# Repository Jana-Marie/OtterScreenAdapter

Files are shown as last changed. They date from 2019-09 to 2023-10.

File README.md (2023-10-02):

# OtterScreenAdapter

It turns out that modern screens/panels like the LP097QX1-SPA1 from LG have a eDP interface, which is only DP (DisplayPort) but without a standard connector. You can buy such a screen for ~40€ and with the OtterScreenAdapter (part cost: ~10€) you can convert it into an external 2048x1536px monitor.

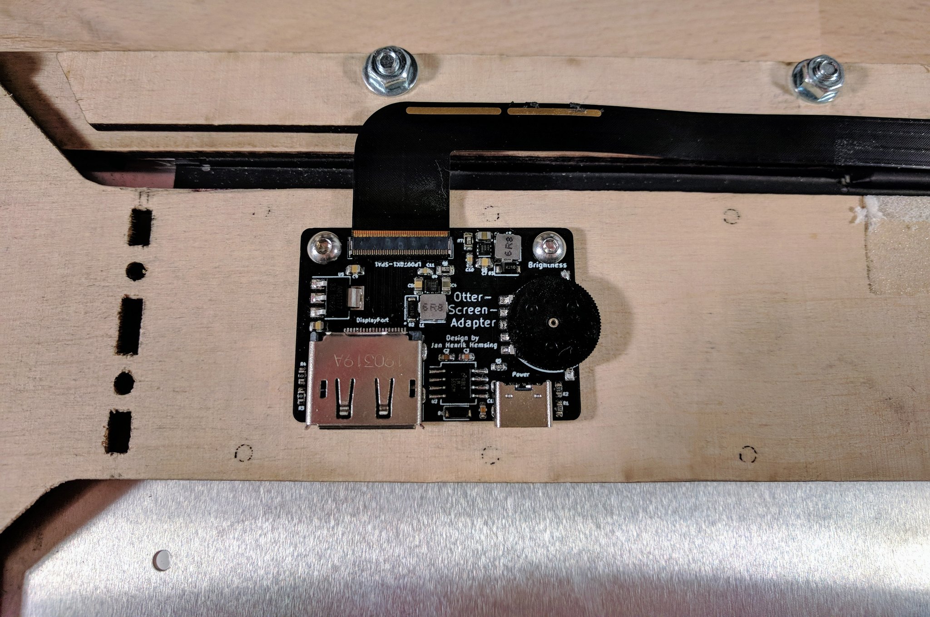
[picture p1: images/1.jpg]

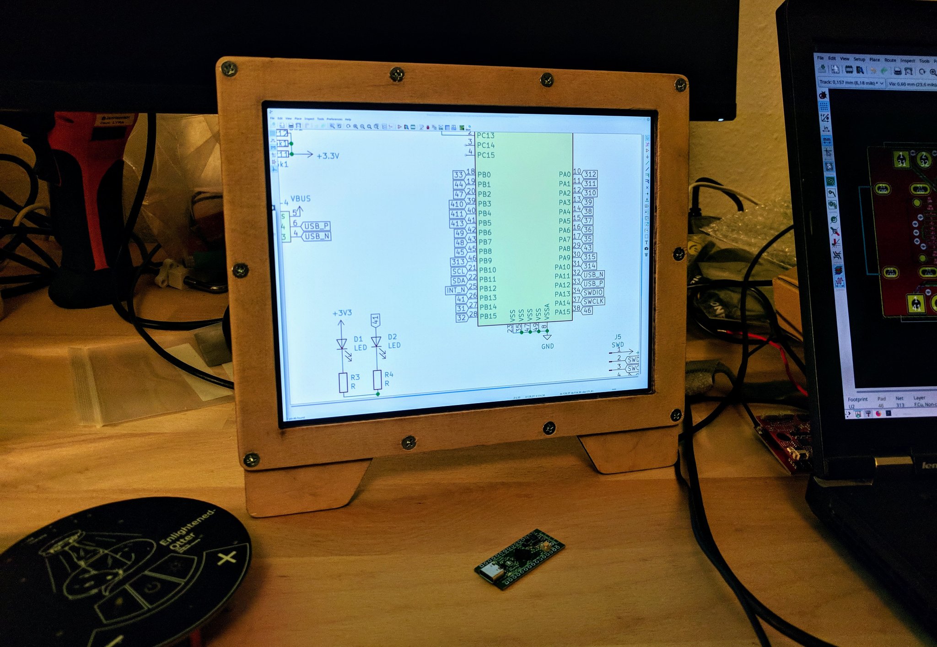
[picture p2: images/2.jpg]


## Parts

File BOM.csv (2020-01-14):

References | Qty | Description | Manufacturer | MPN | Manufacturer | MPN | Manufacturer | MPN | Manufacturer | MPN | Digikey | Mouser | RS | Newark | Farnell | LCSC | Link 1 | Link 2
C10,C11 | 2 | 220nF 50V | Yageo | CC0603KRX7R7BB224 | Murata | GRM188R71E224KA88D |  |  |  |  | 490-1293-1-ND | 81GRM188R71E224KA88 | 6242496 | 68R4772 | 1828900 | C21120
U3,U4 | 2 | TPS61160A |  |  |  |  |  |  |  |  | 296-24308-1-ND | 595TPS61160ADRVR | 1456783 | 33AH5278 | 3006048
C8,C9,C7,C5 | 4 | 470nF 0805 |  |  |  |  |  |  |  |  | 478-1403-1-ND |  |  |  |  | C13967
U5 | 1 | 1117-3.3 |  |  |  |  |  |  |  |  | LM1117DTX-3.3/NOPBCT-ND | 595REG11173.3/2K5 | 8095407 | 29AH7865 | 2111733 | C6186
J1 | 1 | 47272-0001 |  |  |  |  |  |  |  |  | WM19271CT-ND | 538472720001 | 8007021 | 28X2778 | 2396153 |  | https://www.ebay.de/itm/5PCS-X-47272-0001-MOLEX-connector/333130808543 | https://de.aliexpress.com/item/32985577405.html
U2 | 1 | NE555 |  |  |  |  |  |  |  |  | 296-1411-5-ND | 595NE555P | 8234043P | 05M4241 | 9589880 | C7593
R8 | 1 | RK14J12R0A0C | ALPS | RK14J12R0A0C |  |  |  |  |  |  |  | 688-RK14J12R0A0C |  |  |  | C231766
R7,R6 | 2 | 0.8Ohm 0805 |  |  |  |  |  |  |  |  | HCJ0805ZT0R00CT-ND |  |  |  |  | C25267
R5 | 1 | 100Ohm 0603 | Yageo | RC0603FR-07100RL | Panasonic | ERJ-3EKF1000V | Vishay | CRCW0603100RFKEA |  |  | 311-100HRDKR-ND | 71CRCW0603100E3 | 8206748 | 64R5307 | 2303059 | C22775
L2,L1 | 2 | 22uH 4040 |  |  |  |  |  |  |  |  | 732-10762-1-ND | 45522UHF001033E | 1718447P | 26M5905 | 1186787 | C408340
D3,D2,D1 | 2 | SS34 SOD-123 |  |  |  |  |  |  |  |  | SS34LWRVGCT-ND |  |  |  |  | C84632
C6,C4 | 2 | 10uF 0805 | Murata | GRM21BR61C106KE15L |  |  |  |  |  |  | 490-3886-1-ND | 81GRM21BR61C106KE15 | 7236039 | 35R0687 | 1762635 | C15850
C3 | 1 | 1n 0603 | Yageo | CC0603KRX7R9BB102 | Murata | GRM1885C1H102JA01D | Yageo | CC0603KRX7R9BB102 | Murata | GRM188R71H102KA01D | 311-1080-6-ND | 603CC603KRX7R9BB102 | 7235795 | 68R4786 | 1362437 | C1588
C2,C1 | 2 | 100n 0603 | Yageo | CC0603KRX7R9BB104 | Murata | GRM188R71H104KA93D |  |  |  |  | 490-1519-6-ND | 603CC603KRX7R9BB104 | 7235676 | 68R4788 | 8820023 | C14663
J2 | 1 | TYPE-C-31-M-17 | Korean Hroparts Elec | TYPE-C-31-M-17 |  |  |  |  |  |  |  |  |  |  |  | C283540
R4,R3 | 2 | 0Ohm 0603 | Yageo | RC0603JR-070RL | Panasonic | ERJ-3GEY0R00V | Vishay | CRCW06030000Z0EA |  |  | P0.0GCT-ND | 667ERJ3GEY0R00V | 8206736 | 65T8702 | 1469739 | C21189
R2,R1 | 2 | 5K1Ohm 0603 |  |  |  |  |  |  |  |  | YAG2741CT-ND |  |  |  |  | C23186
U1 | 1 | 5022505191 |  |  |  |  |  |  |  |  | WM14452CT-ND | 5385022505191 | 1796502 | 56R1204 | 2442767 |  | https://www.ebay.de/itm/10PCS-X-502250-5191-5022505191-0-3mm-pitch-51Pin-MOLEX-Connector/332230404884 | https://de.aliexpress.com/item/4000026233731.html

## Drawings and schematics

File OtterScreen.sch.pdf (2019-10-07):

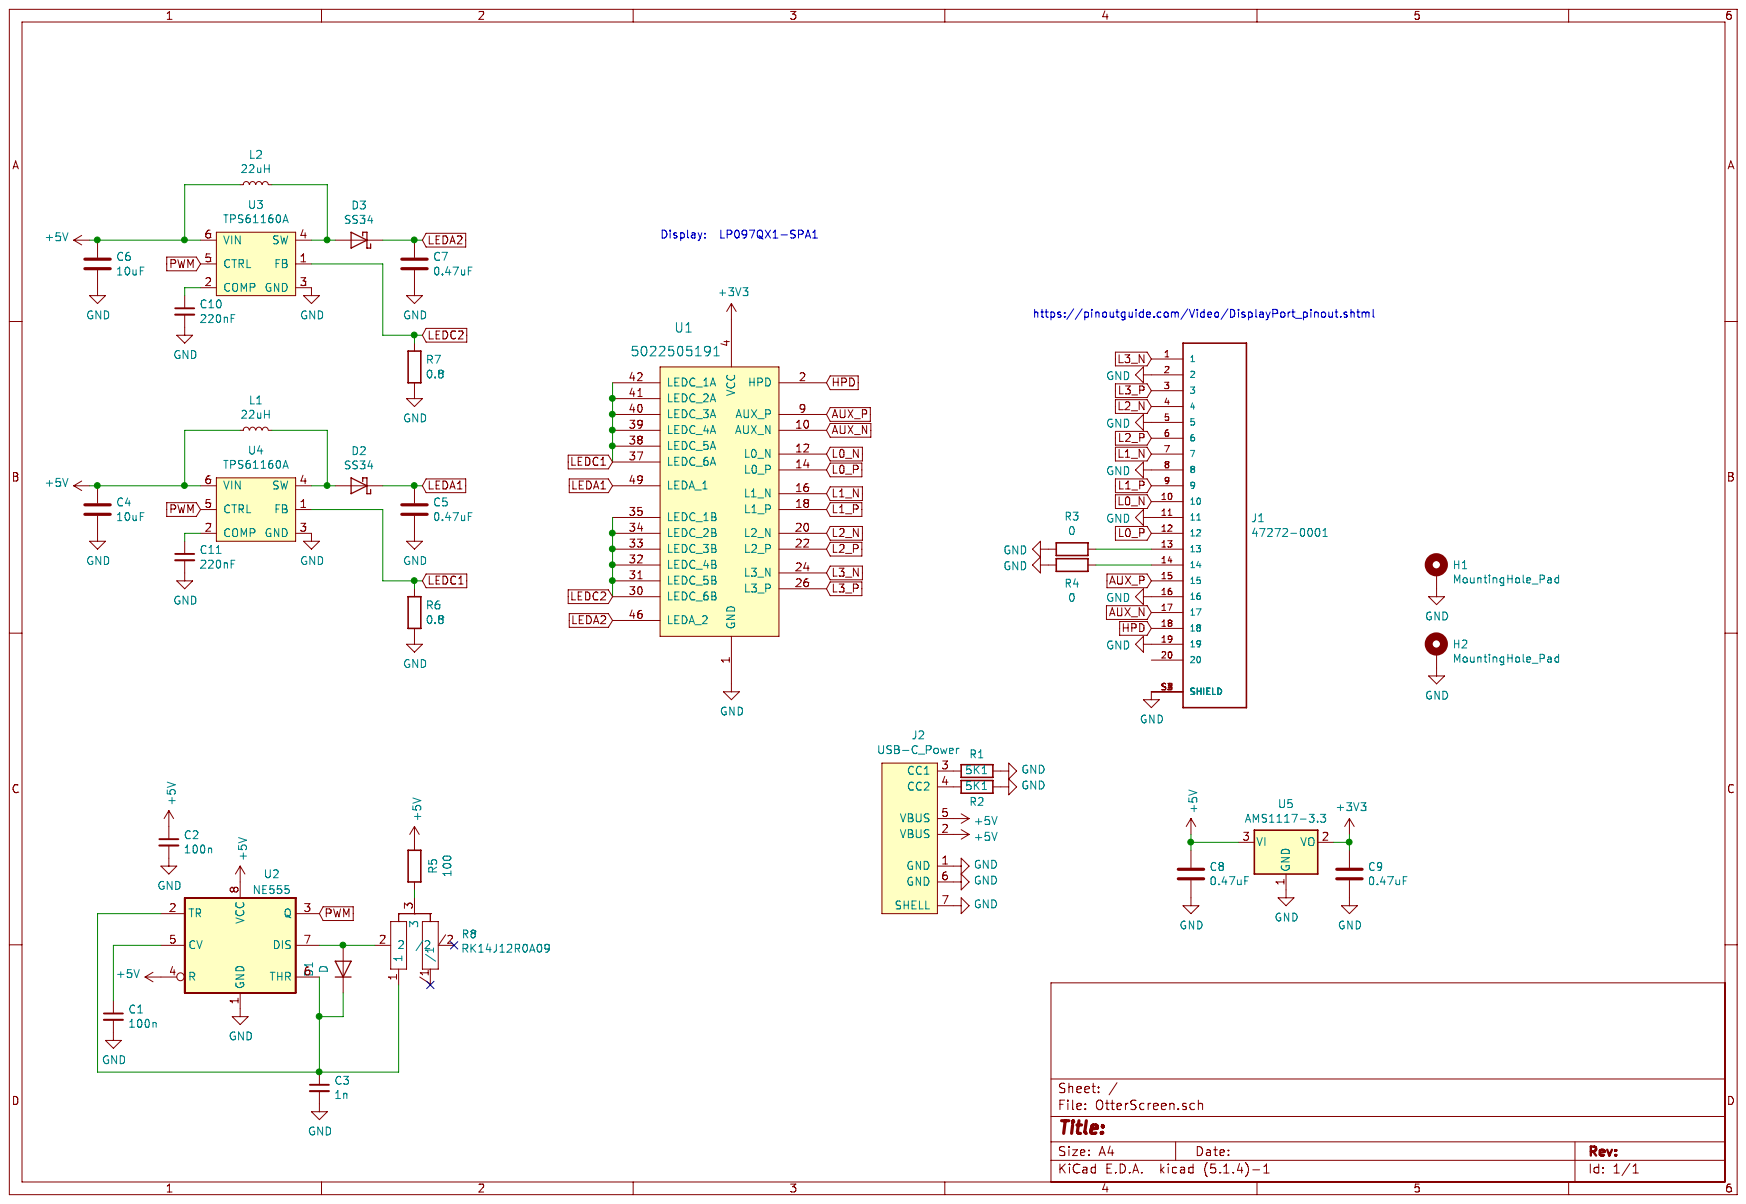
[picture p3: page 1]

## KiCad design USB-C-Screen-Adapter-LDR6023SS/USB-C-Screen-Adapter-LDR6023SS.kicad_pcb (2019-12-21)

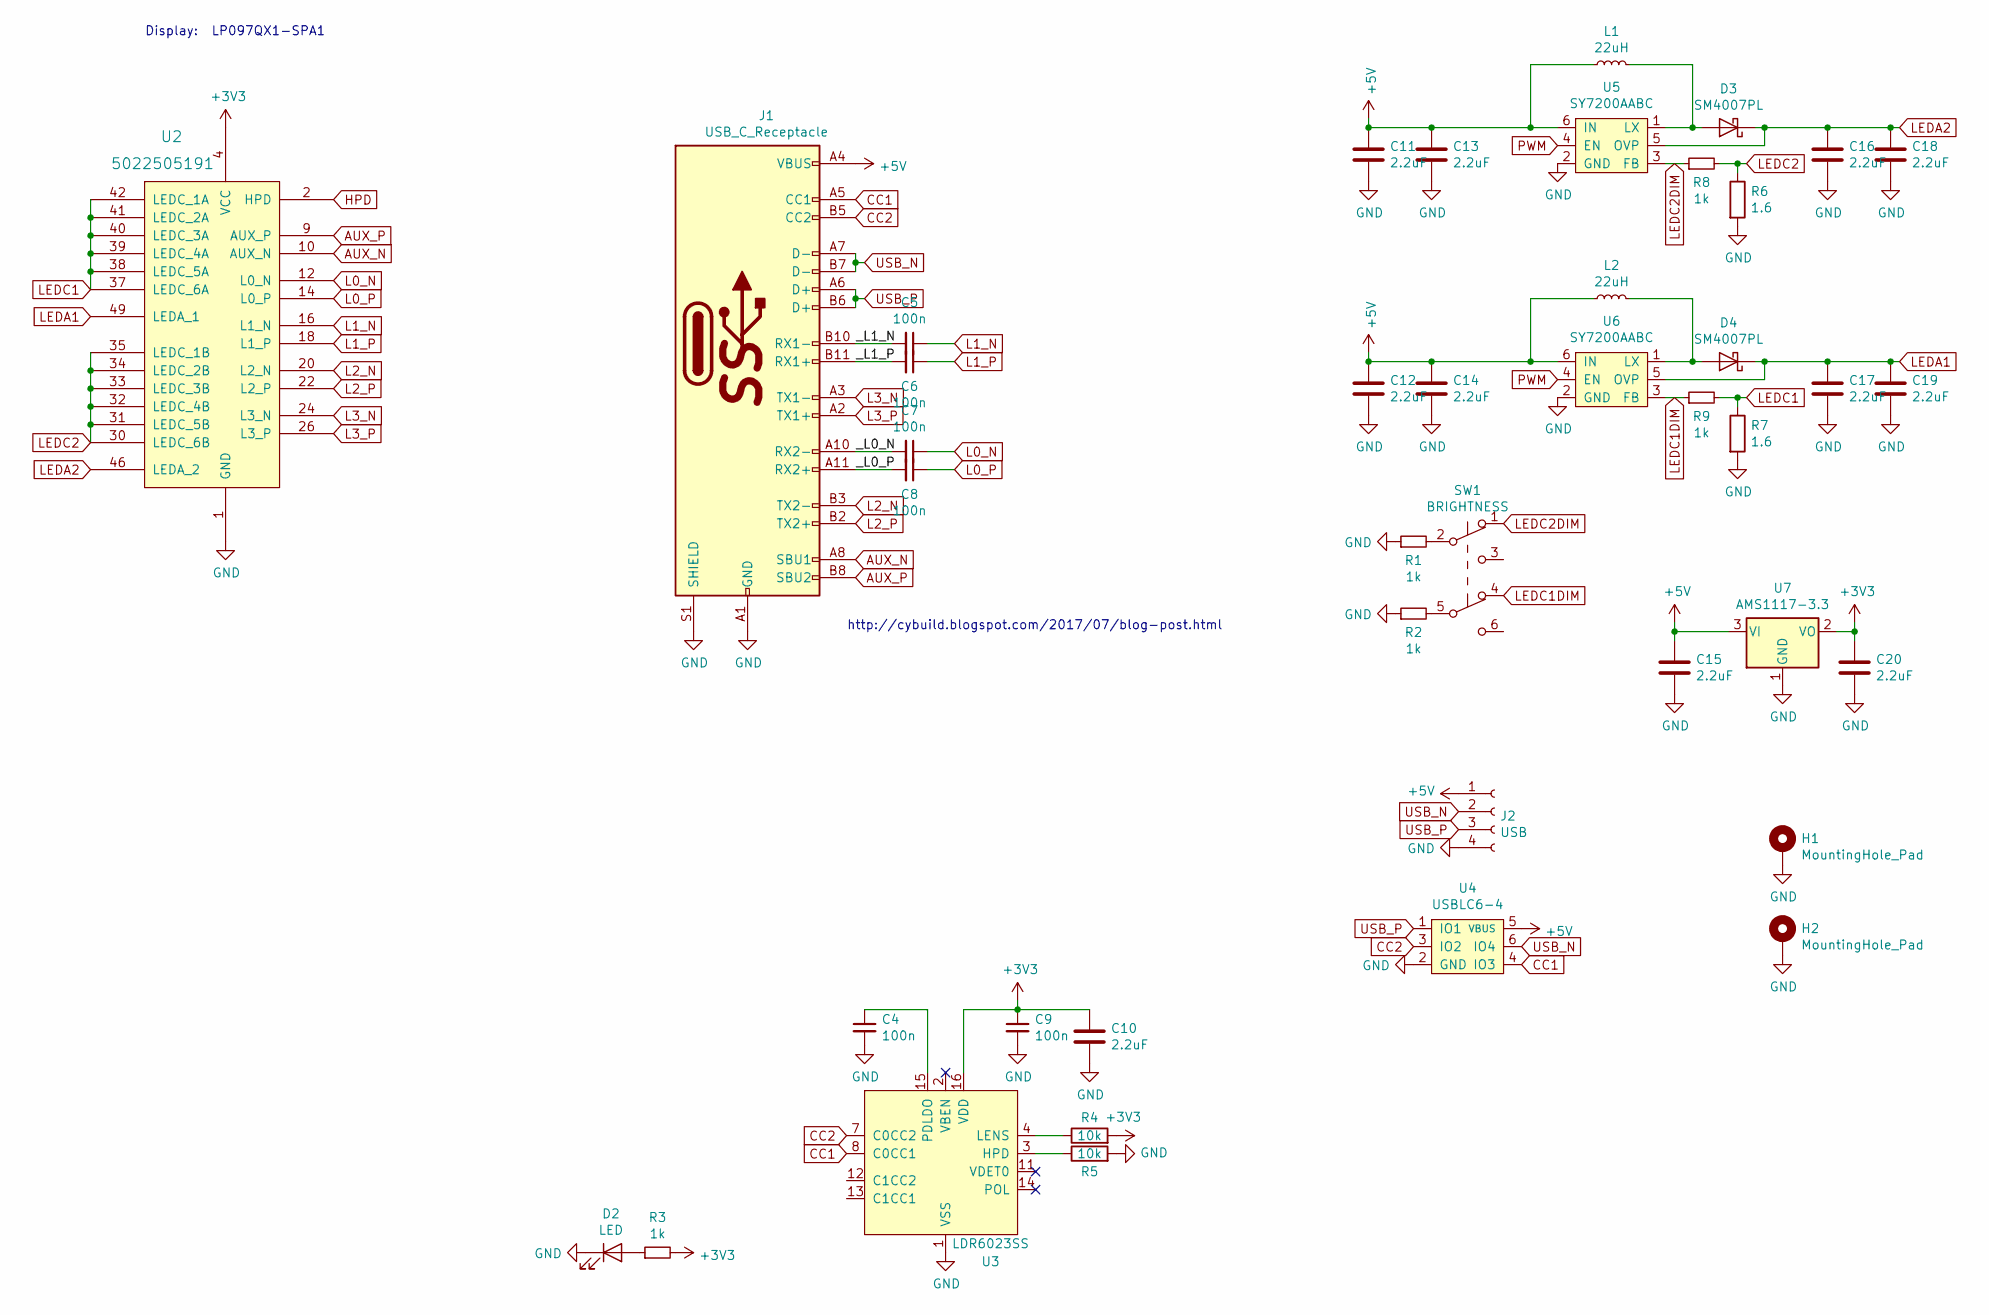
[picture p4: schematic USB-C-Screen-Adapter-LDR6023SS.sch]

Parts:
C4, C9: 100n; C_0603_1608Metric
C5, C6, C7, C8: 100n; C_0402_1005Metric
C10, C11, C12, C13, C14, C15, C16, C17, C18, C19, C20: 2.2uF; C_0805_2012Metric
D2: LED; LED_0603_1608Metric
D3, D4: SM4007PL; D_SOD-123F
H1, H2: MountingHole_Pad; MountingHole_3.2mm_M3
J1: USB_C_Receptacle; USB_C_24P_SMD
J2: USB; PinHeader_1x04_P2.54mm_Vertical
L1, L2: 22uH; L_Taiyo-Yuden_MD-4040
R1, R2, R3, R8, R9: 1k; R_0402_1005Metric
R4, R5: 10k; R_0603_1608Metric
R6, R7: 1.6; R_0805_2012Metric
SW1: BRIGHTNESS; K3-2235S-K1
U2: 5022505191
U3: LDR6023SS; TSSOP-16_4.4x5mm_P0.65mm
U4: USBLC6-4; SOT-23-6
U5, U6: SY7200AABC; SOT-23-6
U7: AMS1117-3.3; SOT-223-3_TabPin2

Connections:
+3V3: C9.1, C10.1, C20.1, R3.2, R4.2, U2.4 (VCC), U2.5 (VCC), U2.6 (VCC), U2.7 (VCC), U3.16 (VDD), U7.2 (VO)
+5V: C11.1, C12.1, C13.1, C14.1, C15.1, J1.A4 (VBUS), J1.A9 (VBUS), J1.B4 (VBUS), J1.B9 (VBUS), J2.1, L1.1, L2.1, U4.5 (VBUS), U5.6 (IN), U6.6 (IN), U7.3 (VI)
/_L0_N: C7.2, J1.A10 (RX2-)
/_L0_P: C8.2, J1.A11 (RX2+)
/_L1_N: C5.2, J1.B10 (RX1-)
/_L1_P: C6.2, J1.B11 (RX1+)
AUX_N: J1.A8 (SBU1), U2.10 (AUX_N)
AUX_P: J1.B8 (SBU2), U2.9 (AUX_P)
CC1: J1.A5 (CC1), U3.8 (C0CC1), U4.4 (IO3)
CC2: J1.B5 (CC2), U3.7 (C0CC2), U4.3 (IO2)
GND: C4.2, C9.2, C10.2, C11.2, C12.2, C13.2, C14.2, C15.2, C16.2, C17.2, C18.2, C19.2, C20.2, D2.1 (K), H1.1, H2.1, J1.A1 (GND), J1.A12 (GND), J1.B1 (GND), J1.B12 (GND), J1.S1 (SHIELD), J2.4, R1.1, R2.1, R5.2, R6.2, R7.2, U2.1 (GND), U2.3 (GND), U2.8 (GND), U2.11 (GND), U2.15 (GND), U2.19 (GND), U2.23 (GND), U2.27 (GND), U2.28 (GND), U2.29 (GND), U2.36 (GND), U2.43 (GND), U2.51 (GND), U3.1 (VSS), U4.2 (GND), U5.2 (GND), U6.2 (GND), U7.1 (GND)
HPD: U2.2 (HPD)
L0_N: C7.1, U2.12 (L0_N)
L0_P: C8.1, U2.14 (L0_P)
L1_N: C5.1, U2.16 (L1_N)
L1_P: C6.1, U2.18 (L1_P)
L2_N: J1.B3 (TX2-), U2.20 (L2_N)
L2_P: J1.B2 (TX2+), U2.22 (L2_P)
L3_N: J1.A3 (TX1-), U2.24 (L3_N)
L3_P: J1.A2 (TX1+), U2.26 (L3_P)
LEDA1: C17.1, C19.1, D4.1 (K), U2.48 (LEDA_1), U2.49 (LEDA_1), U6.5 (OVP)
LEDA2: C16.1, C18.1, D3.1 (K), U2.45 (LEDA_2), U2.46 (LEDA_2), U5.5 (OVP)
LEDC1: R7.1, R9.2, U2.37 (LEDC_6A), U2.38 (LEDC_5A), U2.39 (LEDC_4A), U2.40 (LEDC_3A), U2.41 (LEDC_2A), U2.42 (LEDC_1A)
LEDC1DIM: R9.1, SW1.4 (A), U6.3 (FB)
LEDC2: R6.1, R8.2, U2.30 (LEDC_6B), U2.31 (LEDC_5B), U2.32 (LEDC_4B), U2.33 (LEDC_3B), U2.34 (LEDC_2B), U2.35 (LEDC_1B)
LEDC2DIM: R8.1, SW1.1 (A), U5.3 (FB)
unnamed: C4.1, U3.15 (PDLDO)
unnamed: D2.2 (A), R3.1
unnamed: D3.2 (A), L1.2, U5.1 (LX)
unnamed: D4.2 (A), L2.2, U6.1 (LX)
unnamed: R1.2, SW1.2 (B)
unnamed: R2.2, SW1.5 (B)
unnamed: R4.1, U3.4 (LENS)
unnamed: R5.1, U3.3 (HPD)
PWM: U5.4 (EN), U6.4 (EN)
USB_N: J1.A7 (D-), J1.B7 (D-), J2.2, U4.6 (IO4)
USB_P: J1.A6 (D+), J1.B6 (D+), J2.3, U4.1 (IO1)

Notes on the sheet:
Display: LP097QX1-SPA1
http://cybuild.blogspot.com/2017/07/blog-post.html

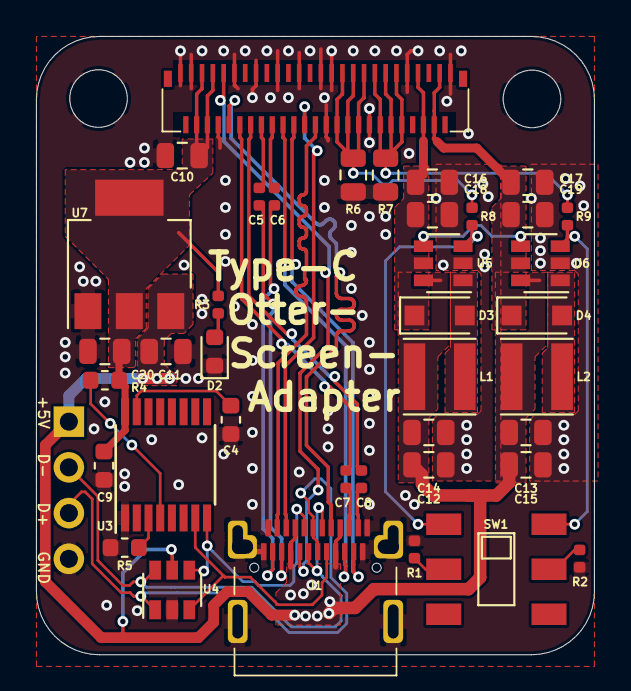
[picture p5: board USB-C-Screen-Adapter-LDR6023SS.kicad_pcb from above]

Board: 2 copper layers, 31.0 x 34.3 mm, 42 parts (0 on the bottom side), 36 nets.

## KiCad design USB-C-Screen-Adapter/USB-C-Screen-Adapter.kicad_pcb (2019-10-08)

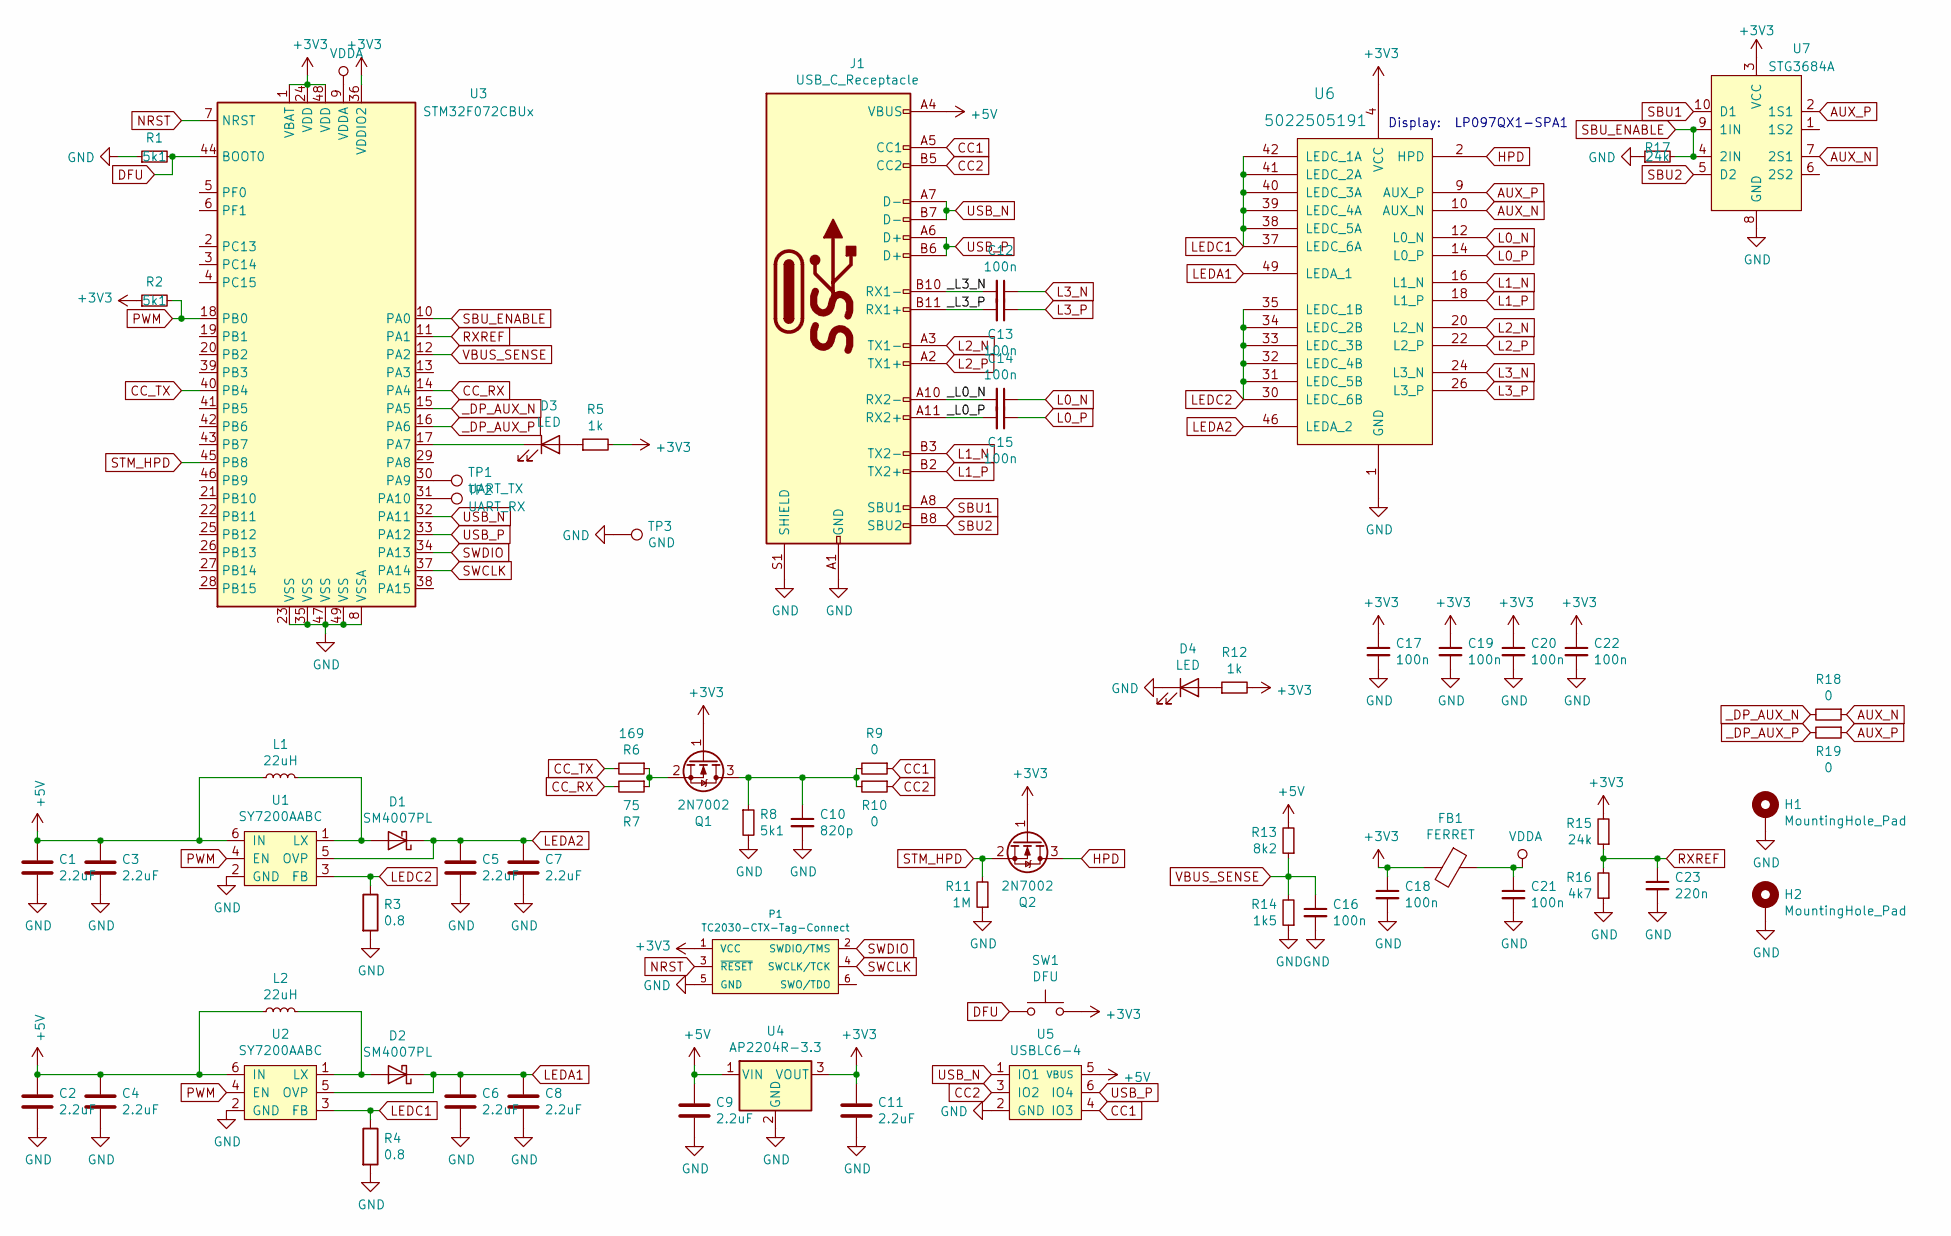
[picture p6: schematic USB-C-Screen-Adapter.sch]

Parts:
C1, C2, C3, C4, C5, C6, C7, C8, C9, C11: 2.2uF; C_0805_2012Metric
C10: 820p; C_0402_1005Metric
C12, C13, C14, C15, C16, C17, C18, C19, C20, C21, C22: 100n; C_0402_1005Metric
C23: 220n; C_0402_1005Metric
D1, D2: SM4007PL; D_SOD-123F
D3, D4: LED; LED_0603_1608Metric
FB1: FERRET; L_0603_1608Metric
H1, H2: MountingHole_Pad; MountingHole_3.2mm_M3
J1: USB_C_Receptacle; USB_C_24P_SMD
L1, L2: 22uH; L_Taiyo-Yuden_MD-4040
P1: TC2030-CTX-Tag-Connect; TC2030
Q1, Q2: 2N7002; SOT-23
R1, R2, R8: 5k1; R_0402_1005Metric
R3, R4: 0.8; R_0805_2012Metric
R5, R12: 1k; R_0402_1005Metric
R6: 169; R_0402_1005Metric
R7: 75; R_0402_1005Metric
R9, R10, R18, R19: 0; R_0402_1005Metric
R11: 1M; R_0402_1005Metric
R13: 8k2; R_0402_1005Metric
R14: 1k5; R_0402_1005Metric
R15, R17: 24k; R_0402_1005Metric
R16: 4k7; R_0402_1005Metric
SW1: DFU; SW_SPST_PTS810
TP1: UART_TX; TestPoint_Pad_D1.0mm
TP2: UART_RX; TestPoint_Pad_D1.0mm
TP3: GND; TestPoint_Pad_D1.0mm
U1, U2: SY7200AABC; SOT-23-6
U3: STM32F072CBUx; QFN-48-1EP_7x7mm_P0.5mm_EP5.6x5.6mm
U4: AP2204R-3.3; SOT-89-3
U5: USBLC6-4; SOT-23-6
U6: 5022505191
U7: STG3684A; QFN10L

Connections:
+3V3: C11.1, C17.1, C18.1, C19.1, C20.1, C22.1, FB1.2, P1.1 (VCC), Q1.1 (G), Q2.1 (G), R2.1, R5.2, R12.2, R15.2, SW1.2, U3.1 (VBAT), U3.24 (VDD), U3.36 (VDDIO2), U3.48 (VDD), U4.3 (VOUT), U6.4 (VCC), U6.5 (VCC), U6.6 (VCC), U6.7 (VCC), U7.3 (VCC)
+5V: C1.1, C2.1, C3.1, C4.1, C9.1, J1.A4 (VBUS), J1.A9 (VBUS), J1.B4 (VBUS), J1.B9 (VBUS), L1.1, L2.1, R13.2, U1.6 (IN), U2.6 (IN), U4.1 (VIN), U5.5 (VBUS)
/_L0_N: C14.2, J1.A10 (RX2-)
/_L0_P: C15.2, J1.A11 (RX2+)
/_L3_N: C12.2, J1.B10 (RX1-)
/_L3_P: C13.2, J1.B11 (RX1+)
AUX_N: R18.1, U6.10 (AUX_N), U7.7 (2S1)
AUX_P: R19.1, U6.9 (AUX_P), U7.2 (1S1)
CC1: J1.A5 (CC1), R9.1, U5.4 (IO3)
CC2: J1.B5 (CC2), R10.1, U5.3 (IO2)
CC_RX: R7.2, U3.14 (PA4)
CC_TX: R6.2, U3.40 (PB4)
DFU: R1.2, SW1.1, U3.44 (BOOT0)
GND: C1.2, C2.2, C3.2, C4.2, C5.2, C6.2, C7.2, C8.2, C9.2, C10.2, C11.2, C16.2, C17.2, C18.2, C19.2, C20.2, C21.2, C22.2, C23.2, D4.1 (K), H1.1, H2.1, J1.A1 (GND), J1.A12 (GND), J1.B1 (GND), J1.B12 (GND), J1.S1 (SHIELD), P1.5 (GND), R1.1, R3.2, R4.2, R8.2, R11.1, R14.1, R16.1, R17.1, TP3.1, U1.2 (GND), U2.2 (GND), U3.8 (VSSA), U3.23 (VSS), U3.35 (VSS), U3.47 (VSS), U3.49 (VSS), U4.2 (GND), U5.2 (GND), U6.1 (GND), U6.3 (GND), U6.8 (GND), U6.11 (GND), U6.15 (GND), U6.19 (GND), U6.23 (GND), U6.27 (GND), U6.28 (GND), U6.29 (GND), U6.36 (GND), U6.43 (GND), U6.51 (GND), U7.8 (GND)
HPD: Q2.3 (D), U6.2 (HPD)
L0_N: C14.1, U6.12 (L0_N)
L0_P: C15.1, U6.14 (L0_P)
L1_N: J1.B3 (TX2-), U6.16 (L1_N)
L1_P: J1.B2 (TX2+), U6.18 (L1_P)
L2_N: J1.A3 (TX1-), U6.20 (L2_N)
L2_P: J1.A2 (TX1+), U6.22 (L2_P)
L3_N: C12.1, U6.24 (L3_N)
L3_P: C13.1, U6.26 (L3_P)
LEDA1: C6.1, C8.1, D2.1 (K), U2.5 (OVP), U6.48 (LEDA_1), U6.49 (LEDA_1)
LEDA2: C5.1, C7.1, D1.1 (K), U1.5 (OVP), U6.45 (LEDA_2), U6.46 (LEDA_2)
LEDC1: R4.1, U2.3 (FB), U6.37 (LEDC_6A), U6.38 (LEDC_5A), U6.39 (LEDC_4A), U6.40 (LEDC_3A), U6.41 (LEDC_2A), U6.42 (LEDC_1A)
LEDC2: R3.1, U1.3 (FB), U6.30 (LEDC_6B), U6.31 (LEDC_5B), U6.32 (LEDC_4B), U6.33 (LEDC_3B), U6.34 (LEDC_2B), U6.35 (LEDC_1B)
NRST: P1.3 (~RESET~), U3.7 (NRST)
unnamed: C10.1, Q1.3 (D), R8.1, R9.2, R10.2
unnamed: D1.2 (A), L1.2, U1.1 (LX)
unnamed: D2.2 (A), L2.2, U2.1 (LX)
unnamed: D3.1 (K), U3.17 (PA7)
unnamed: D3.2 (A), R5.1
unnamed: D4.2 (A), R12.1
unnamed: Q1.2 (S), R6.1, R7.1
unnamed: TP1.1, U3.30 (PA9)
unnamed: TP2.1, U3.31 (PA10)
PWM: R2.2, U1.4 (EN), U2.4 (EN), U3.18 (PB0)
RXREF: C23.1, R15.1, R16.2, U3.11 (PA1)
SBU1: J1.A8 (SBU1), U7.10 (D1)
SBU2: J1.B8 (SBU2), U7.5 (D2)
SBU_ENABLE: R17.2, U3.10 (PA0), U7.4 (2IN), U7.9 (1IN)
STM_HPD: Q2.2 (S), R11.2, U3.45 (PB8)
SWCLK: P1.4 (SWCLK/TCK), U3.37 (PA14)
SWDIO: P1.2 (SWDIO/TMS), U3.34 (PA13)
USB_N: J1.A7 (D-), J1.B7 (D-), U3.32 (PA11), U5.1 (IO1)
USB_P: J1.A6 (D+), J1.B6 (D+), U3.33 (PA12), U5.6 (IO4)
VBUS_SENSE: C16.1, R13.1, R14.2, U3.12 (PA2)
VDDA: C21.1, FB1.1, U3.9 (VDDA)
_DP_AUX_N: R18.2, U3.15 (PA5)
_DP_AUX_P: R19.2, U3.16 (PA6)

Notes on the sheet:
Display: LP097QX1-SPA1

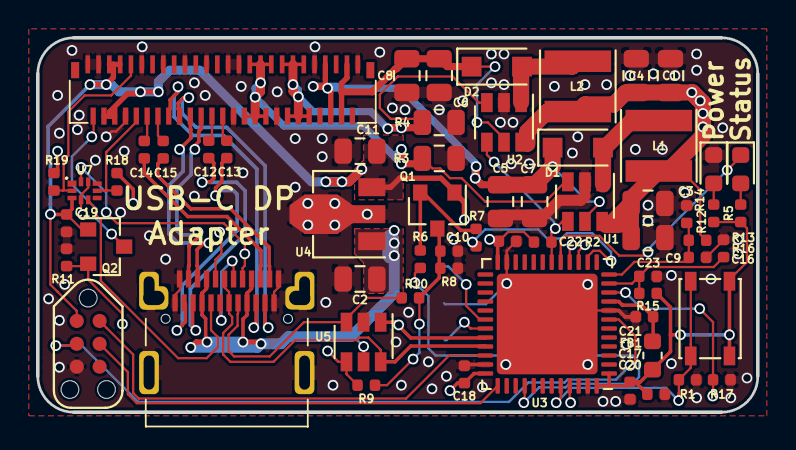
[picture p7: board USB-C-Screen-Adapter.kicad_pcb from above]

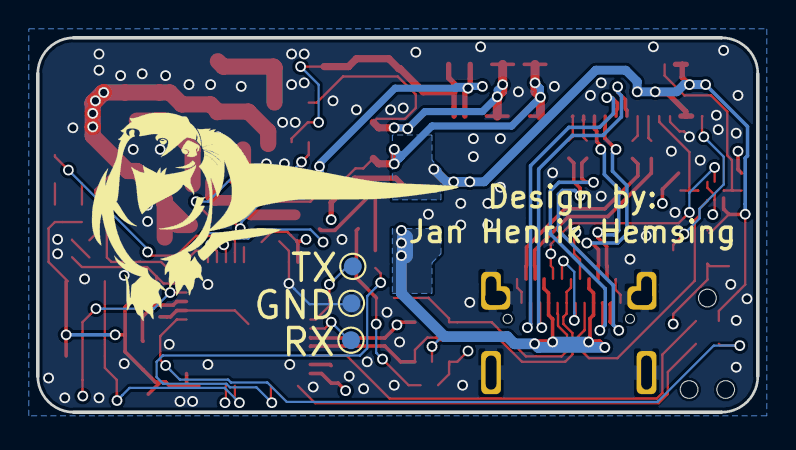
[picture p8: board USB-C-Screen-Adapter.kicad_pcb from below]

Board: 4 copper layers, 40.0 x 20.8 mm, 64 parts (3 on the bottom side), 51 nets.

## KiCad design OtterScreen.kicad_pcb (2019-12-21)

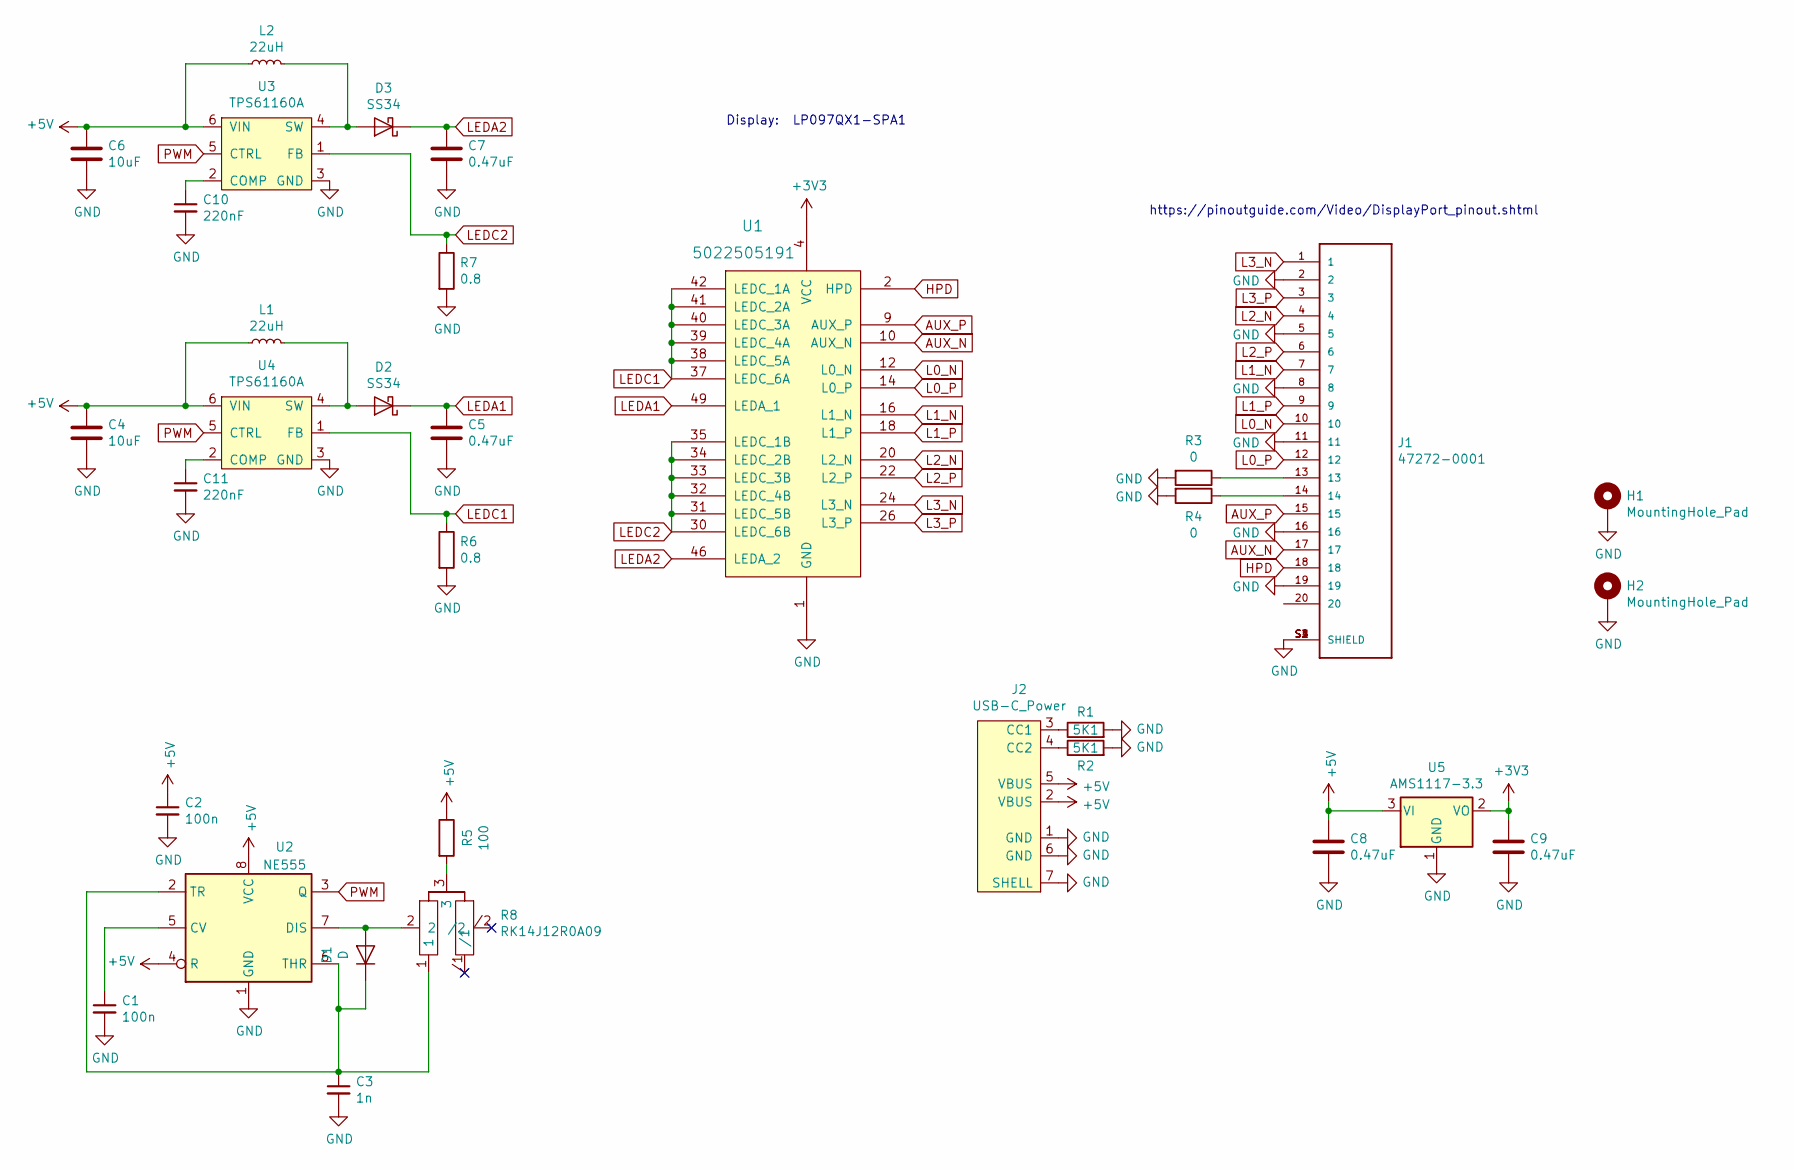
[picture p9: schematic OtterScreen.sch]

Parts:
C1, C2: 100n; C_0603_1608Metric
C3: 1n; C_0603_1608Metric
C4, C6: 10uF; C_0805_2012Metric
C5, C7, C8, C9: 0.47uF; C_0805_2012Metric
C10, C11: 220nF; C_0603_1608Metric
D1: D; D_SOD-123F
D2, D3: SS34; D_SOD-123F
H1, H2: MountingHole_Pad; MountingHole_3.2mm_M3
J1: 47272-0001; MOLEX_47272-0001
J2: USB-C_Power
L1, L2: 22uH; L_Taiyo-Yuden_MD-4040
R1, R2: 5K1; R_0603_1608Metric
R3, R4: 0; R_0603_1608Metric
R5: 100; R_0603_1608Metric
R6, R7: 0.8; R_0805_2012Metric
R8: RK14J12R0A09
U1: 5022505191
U2: NE555; SO-8_5.3x6.2mm_P1.27mm
U3, U4: TPS61160A; WSON-6-1EP_2x2mm_P0.65mm_EP1x1.6mm
U5: AMS1117-3.3; SOT-223-3_TabPin2

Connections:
+3V3: C9.1, U1.4 (VCC), U1.5 (VCC), U1.6 (VCC), U1.7 (VCC), U5.2 (VO)
+5V: C2.1, C4.1, C6.1, C8.1, J2.2 (VBUS), J2.5 (VBUS), L1.1, L2.1, R5.1, U2.4 (R), U2.8 (VCC), U3.6 (VIN), U4.6 (VIN), U5.3 (VI)
AUX_N: J1.17, U1.10 (AUX_N)
AUX_P: J1.15, U1.9 (AUX_P)
GND: C1.2, C2.2, C3.2, C4.2, C5.2, C6.2, C7.2, C8.2, C9.2, C10.2, C11.2, H1.1, H2.1, J1.2, J1.5, J1.8, J1.11, J1.16, J1.19, J1.S1 (SHIELD), J1.S2 (SHIELD), J1.S3 (SHIELD), J1.S4 (SHIELD), J2.1 (GND), J2.6 (GND), J2.7 (SHELL), R1.2, R2.2, R3.2, R4.2, R6.2, R7.2, U1.1 (GND), U1.3 (GND), U1.8 (GND), U1.11 (GND), U1.15 (GND), U1.19 (GND), U1.23 (GND), U1.27 (GND), U1.28 (GND), U1.29 (GND), U1.36 (GND), U1.43 (GND), U1.51 (GND), U2.1 (GND), U3.3 (GND), U3.7 (TP), U4.3 (GND), U4.7 (TP), U5.1 (GND)
HPD: J1.18, U1.2 (HPD)
L0_N: J1.10, U1.12 (L0_N)
L0_P: J1.12, U1.14 (L0_P)
L1_N: J1.7, U1.16 (L1_N)
L1_P: J1.9, U1.18 (L1_P)
L2_N: J1.4, U1.20 (L2_N)
L2_P: J1.6, U1.22 (L2_P)
L3_N: J1.1, U1.24 (L3_N)
L3_P: J1.3, U1.26 (L3_P)
LEDA1: C5.1, D2.1 (K), U1.48 (LEDA_1), U1.49 (LEDA_1)
LEDA2: C7.1, D3.1 (K), U1.45 (LEDA_2), U1.46 (LEDA_2)
LEDC1: R6.1, U1.37 (LEDC_6A), U1.38 (LEDC_5A), U1.39 (LEDC_4A), U1.40 (LEDC_3A), U1.41 (LEDC_2A), U1.42 (LEDC_1A), U4.1 (FB)
LEDC2: R7.1, U1.30 (LEDC_6B), U1.31 (LEDC_5B), U1.32 (LEDC_4B), U1.33 (LEDC_3B), U1.34 (LEDC_2B), U1.35 (LEDC_1B), U3.1 (FB)
unnamed: C1.1, U2.5 (CV)
unnamed: C3.1, D1.1 (K), R8.1, U2.2 (TR), U2.6 (THR)
unnamed: C10.1, U3.2 (COMP)
unnamed: C11.1, U4.2 (COMP)
unnamed: D1.2 (A), R8.2, U2.7 (DIS)
unnamed: D2.2 (A), L1.2, U4.4 (SW)
unnamed: D3.2 (A), L2.2, U3.4 (SW)
unnamed: J1.13, R3.1
unnamed: J1.14, R4.1
unnamed: J2.3 (CC1), R1.1
unnamed: J2.4 (CC2), R2.1
unnamed: R5.2, R8.3
PWM: U2.3 (Q), U3.5 (CTRL), U4.5 (CTRL)

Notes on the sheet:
Display: LP097QX1-SPA1
https://pinoutguide.com/Video/DisplayPort_pinout.shtml

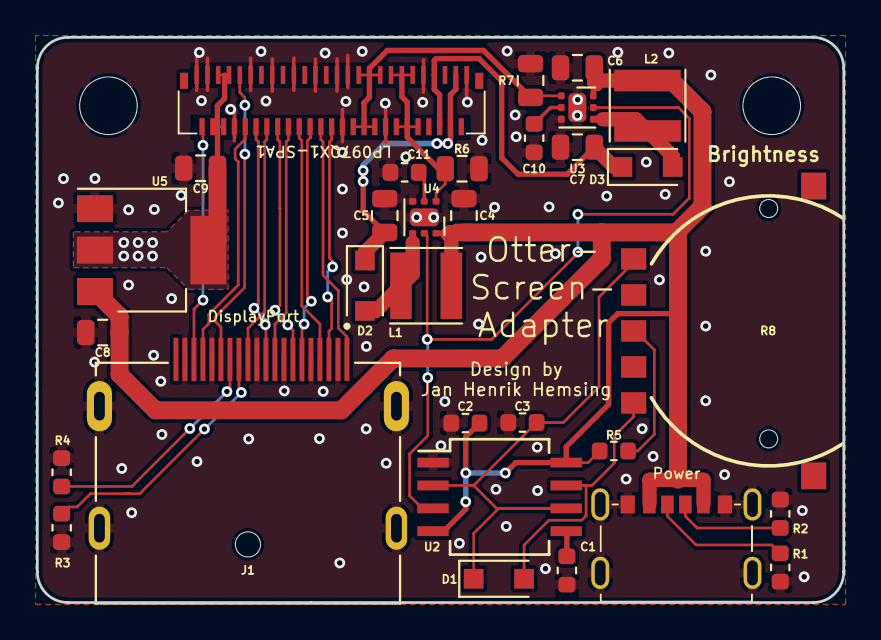
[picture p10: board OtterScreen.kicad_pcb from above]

Board: 2 copper layers, 44.8 x 31.4 mm, 33 parts (0 on the bottom side), 31 nets.

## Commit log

2019-08-12 updated files
    [OtterScreen.kicad_pcb, OtterScreen.sch]
2019-09-03 fixed bugs, added ams1117
    [OtterScreen-B.Cu.gbl, OtterScreen-B.Mask.gbs, OtterScreen-B.Paste.gbp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]
2019-09-24 added bom
    [BOM.csv]
2019-09-27 updated bom
    [BOM.csv]
2019-10-07 add .pdf of schematic and layout
2019-10-07 added USB-C version
    [OtterScreen.sch, USB-C-Screen-Adapter.kicad_pcb, USB-C-Screen-Adapter.sch]
2019-10-08 redone layout
    [USB-C-Screen-Adapter.kicad_pcb]
2019-10-08 finalized layout
    [USB-C-Screen-Adapter.kicad_pcb]
2019-10-08 moved files, finalized silkscreen, added gerber
    [OtterScreen.sch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]
2019-10-08 moved files
    [OtterScreen.sch, USB-C-Screen-Adapter.kicad_pcb, USB-C-Screen-Adapter.sch]
2019-12-16 added new usb-c adapter
    [USB-C-Screen-Adapter-LDR6023SS.kicad_pcb, USB-C-Screen-Adapter-LDR6023SS.sch]
2019-12-16 updated schematic
    [USB-C-Screen-Adapter-LDR6023SS.kicad_pcb, USB-C-Screen-Adapter-LDR6023SS.sch]
2019-12-21 updated layout
    [USB-C-Screen-Adapter-LDR6023SS.kicad_pcb, USB-C-Screen-Adapter-LDR6023SS.sch]
2019-12-21 fixed otter-screen-adapter, added gerber
    [OtterScreen-B_Cu.gbl, OtterScreen-B_Mask.gbs, OtterScreen-B_Paste.gbp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]
2019-12-22 updated gerber
    [OtterScreen-B_Cu.gbl, OtterScreen-B_Mask.gbs, OtterScreen-B_Paste.gbp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]
2019-12-22 removed old gerber
    [OtterScreen-B.Cu.gbl, OtterScreen-B.Mask.gbs, OtterScreen-B.Paste.gbp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]
